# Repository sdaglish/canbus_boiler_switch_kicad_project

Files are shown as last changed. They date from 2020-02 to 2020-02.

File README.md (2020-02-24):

# Canbus Boiler Switch KiCad Project

## Version History

* v1.0
    * 23 Feb 2020
        * First manufactured prototype of board
        * Developed for prototyping
        * Developed for extending to sensor, ect. via header pins
* v1.1
    * 23 Feb 2020
        * Adding version history to readme
        * Removed mfr files from project
        * Removed backup files from project
        * Added sheet information to schematic files

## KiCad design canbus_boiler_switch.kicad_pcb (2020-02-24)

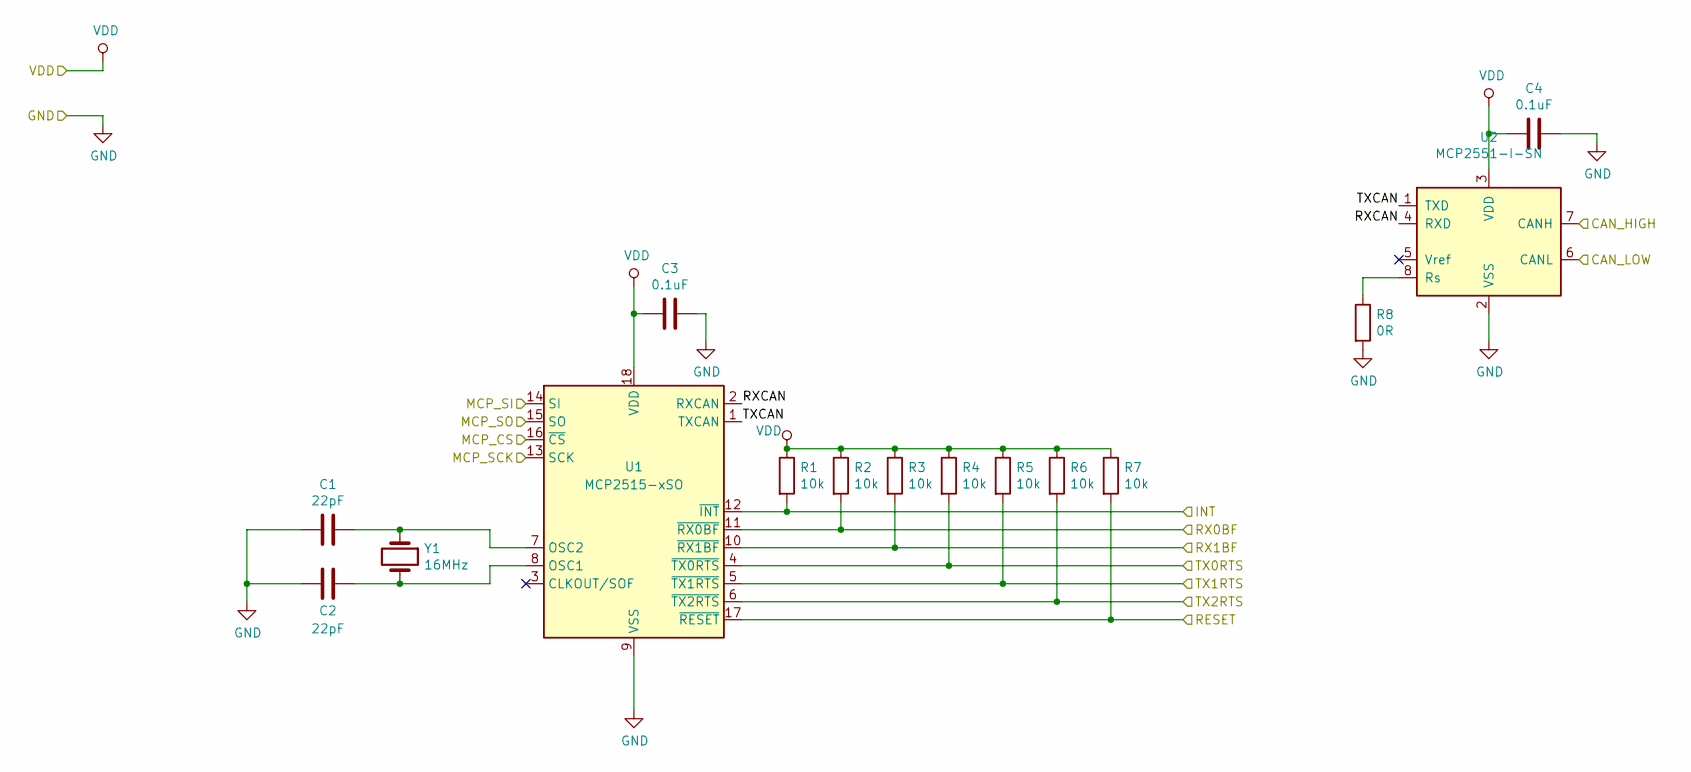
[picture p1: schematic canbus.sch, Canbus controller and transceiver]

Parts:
C1, C2: 22pF; C_1206_3216Metric
C3, C4: 0.1uF; C_1206_3216Metric
R1, R2, R3, R4, R5, R6, R7: 10k; R_1206_3216Metric
R8: 0R; R_1206_3216Metric
U1: MCP2515-xSO; SOIC-18W_7.5x11.6mm_P1.27mm
U2: MCP2551-I-SN; SOIC-8_3.9x4.9mm_P1.27mm
Y1: 16MHz; Crystal_SMD_HC49-SD_HandSoldering

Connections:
/canbus/INT: R1.2, U1.12 (~INT); also elsewhere on the board
/canbus/MCP_SCK: U1.13 (SCK); also elsewhere on the board
/canbus/MCP_SI: U1.14 (SI); also elsewhere on the board
/canbus/MCP_SO: U1.15 (SO); also elsewhere on the board
/canbus/RESET: R7.2, U1.17 (~RESET); also elsewhere on the board
/canbus/RX0BF: R2.2, U1.11 (~RX0BF); also elsewhere on the board
/canbus/RX1BF: R3.2, U1.10 (~RX1BF); also elsewhere on the board
/canbus/RXCAN: U1.2 (RXCAN), U2.4 (RXD)
/canbus/TX0RTS: R4.2, U1.4 (~TX0RTS); also elsewhere on the board
/canbus/TX1RTS: R5.2, U1.5 (~TX1RTS); also elsewhere on the board
/canbus/TX2RTS: R6.2, U1.6 (~TX2RTS); also elsewhere on the board
/canbus/TXCAN: U1.1 (TXCAN), U2.1 (TXD)
/mircoprocessor/CS: U1.16 (~CS); also elsewhere on the board
/rj12_connections/CAN_H: U2.7 (CANH); also elsewhere on the board
/rj12_connections/CAN_L: U2.6 (CANL); also elsewhere on the board
GND: C1.2, C2.2, C3.1, C4.1, R8.2, U1.9 (VSS), U2.2 (VSS); also elsewhere on the board
unnamed: C1.1, U1.7 (OSC2), Y1.1
unnamed: C2.1, U1.8 (OSC1), Y1.2
unnamed: R8.1, U2.8 (Rs)
VDD: C3.2, C4.2, R1.1, R2.1, R3.1, R4.1, R5.1, R6.1, R7.1, U1.18 (VDD), U2.3 (VDD); also elsewhere on the board

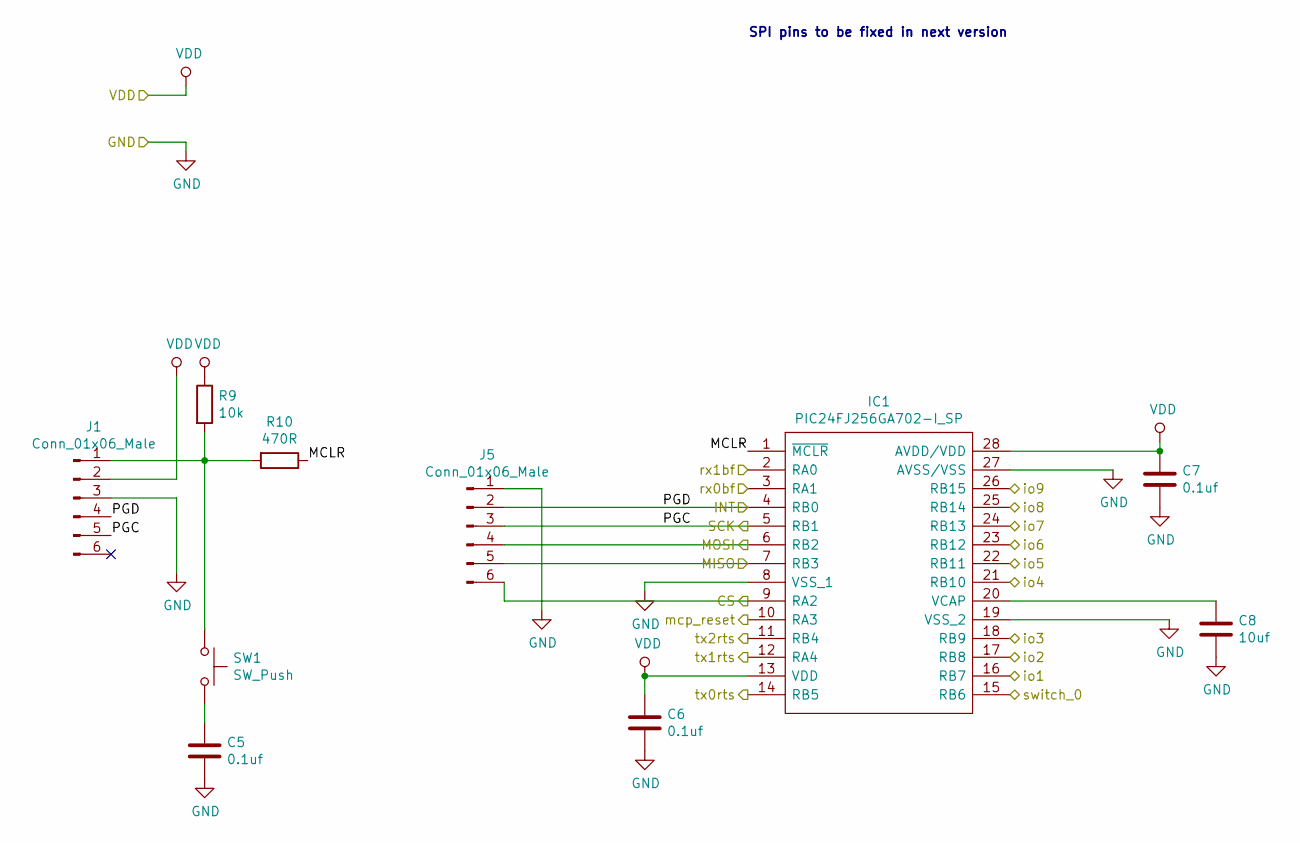
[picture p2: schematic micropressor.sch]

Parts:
C5, C6, C7: 0.1uf; C_1206_3216Metric
C8: 10uf; C_1206_3216Metric
IC1: PIC24FJ256GA702-I_SP; SOIC127P1030X265-28N; Manufacturer_Part_Number PIC24FJ256GA702-I/SP; Mouser Part Number 579-24FJ256GA702ISP
J1, J5: Conn_01x06_Male; PinHeader_1x06_P2.54mm_Vertical
R9: 10k; R_1206_3216Metric
R10: 470R; R_1206_3216Metric
SW1: SW_Push; SW_PUSH_6mm

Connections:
/canbus/INT: IC1.4 (RB0), J1.4, J5.2; also elsewhere on the board
/canbus/MCP_SCK: IC1.5 (RB1), J1.5, J5.3; also elsewhere on the board
/canbus/MCP_SI: IC1.6 (RB2), J5.4; also elsewhere on the board
/canbus/MCP_SO: IC1.7 (RB3), J5.5; also elsewhere on the board
/canbus/RESET: IC1.10 (RA3); also elsewhere on the board
/canbus/RX0BF: IC1.3 (RA1); also elsewhere on the board
/canbus/RX1BF: IC1.2 (RA0); also elsewhere on the board
/canbus/TX0RTS: IC1.14 (RB5); also elsewhere on the board
/canbus/TX1RTS: IC1.12 (RA4); also elsewhere on the board
/canbus/TX2RTS: IC1.11 (RB4); also elsewhere on the board
/io/io1: IC1.16 (RB7); also elsewhere on the board
/io/io2: IC1.17 (RB8); also elsewhere on the board
/io/io3: IC1.18 (RB9); also elsewhere on the board
/io/io4: IC1.21 (RB10); also elsewhere on the board
/io/io5: IC1.22 (RB11); also elsewhere on the board
/io/io6: IC1.23 (RB12); also elsewhere on the board
/io/io7: IC1.24 (RB13); also elsewhere on the board
/io/io8: IC1.25 (RB14); also elsewhere on the board
/io/io9: IC1.26 (RB15); also elsewhere on the board
/io/switch_0: IC1.15 (RB6); also elsewhere on the board
/mircoprocessor/CS: IC1.9 (RA2), J5.6; also elsewhere on the board
/mircoprocessor/MCLR: IC1.1 (~MCLR), R10.1
GND: C5.2, C6.2, C7.2, C8.2, IC1.8 (VSS_1), IC1.19 (VSS_2), IC1.27 (AVSS/VSS), J1.3, J5.1; also elsewhere on the board
unnamed: C5.1, SW1.2
unnamed: C8.1, IC1.20 (VCAP)
unnamed: J1.1, R9.2, R10.2, SW1.1
VDD: C6.1, C7.1, IC1.13 (VDD), IC1.28 (AVDD/VDD), J1.2, R9.1; also elsewhere on the board

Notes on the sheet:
SPI pins to be fixed in next version

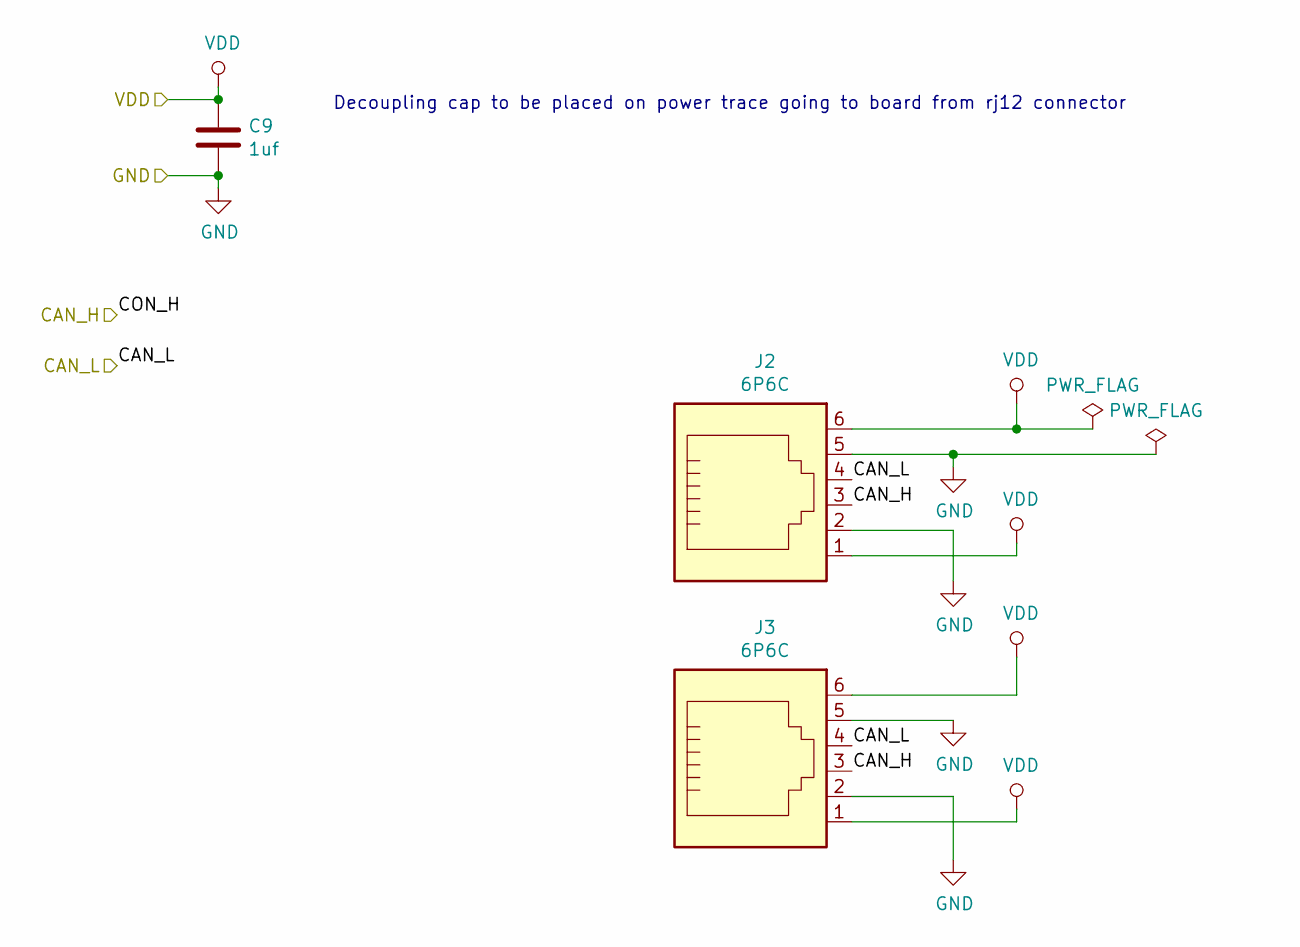
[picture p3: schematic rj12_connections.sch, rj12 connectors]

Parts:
C9: 1uf; C_1206_3216Metric
J2, J3: 6P6C; RJ12_Amphenol_54601

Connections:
/rj12_connections/CAN_H: J2.3, J3.3; also elsewhere on the board
/rj12_connections/CAN_L: J2.4, J3.4; also elsewhere on the board
GND: C9.2, J2.2, J2.5, J3.2, J3.5; also elsewhere on the board
VDD: C9.1, J2.1, J2.6, J3.1, J3.6; also elsewhere on the board

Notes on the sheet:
Decoupling cap to be placed on power trace going to board from rj12 connector

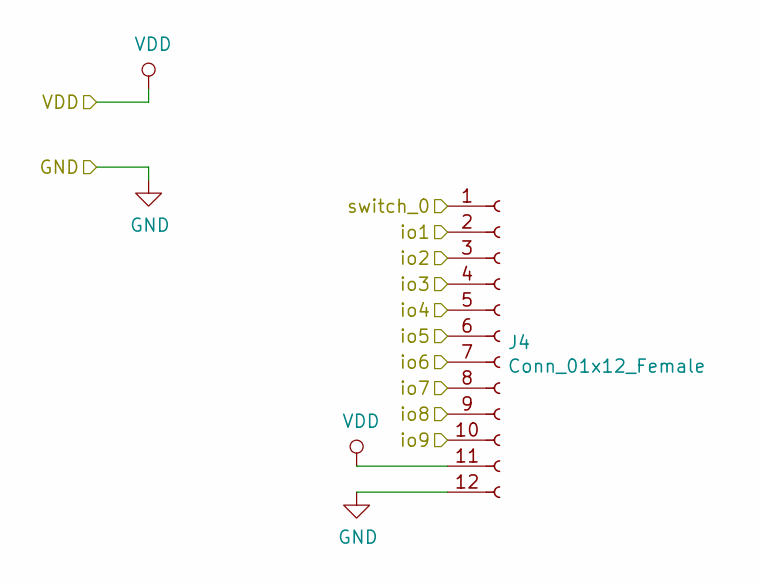
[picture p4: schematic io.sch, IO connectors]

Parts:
J4: Conn_01x12_Female; PinSocket_1x12_P2.54mm_Vertical

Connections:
/io/io1: J4.2; also elsewhere on the board
/io/io2: J4.3; also elsewhere on the board
/io/io3: J4.4; also elsewhere on the board
/io/io4: J4.5; also elsewhere on the board
/io/io5: J4.6; also elsewhere on the board
/io/io6: J4.7; also elsewhere on the board
/io/io7: J4.8; also elsewhere on the board
/io/io8: J4.9; also elsewhere on the board
/io/io9: J4.10; also elsewhere on the board
/io/switch_0: J4.1; also elsewhere on the board
GND: J4.12; also elsewhere on the board
VDD: J4.11; also elsewhere on the board

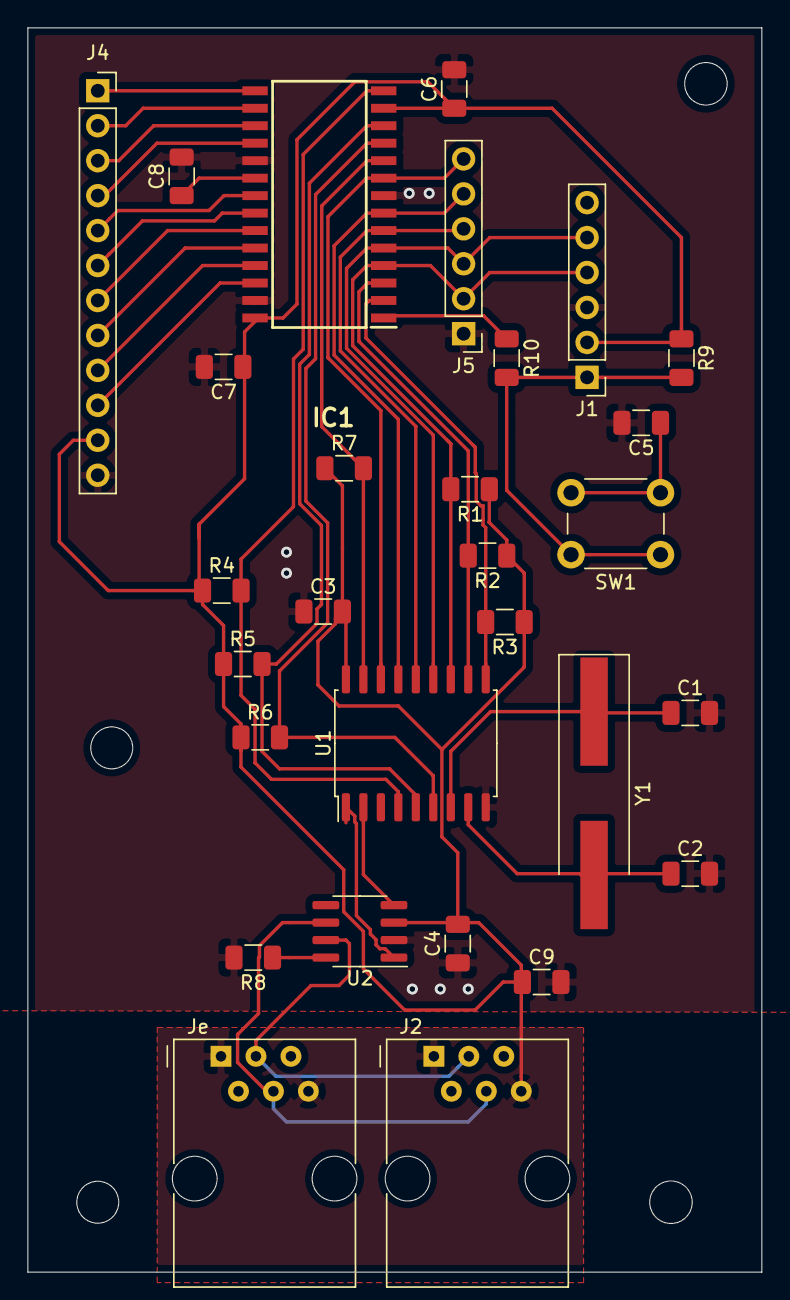
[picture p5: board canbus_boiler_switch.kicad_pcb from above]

Board: 2 copper layers, 53.3 x 90.4 mm, 29 parts (0 on the bottom side), 34 nets.

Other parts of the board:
Je: 6P6C; RJ12_Amphenol_54601

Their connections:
/rj12_connections/CAN_H: Je.3; also elsewhere on the board
/rj12_connections/CAN_L: Je.4; also elsewhere on the board
GND: Je.2, Je.5; also elsewhere on the board
VDD: Je.1, Je.6; also elsewhere on the board

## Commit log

2019-10-19 Project creation
    [canbus_boiler_switch.kicad_pcb, canbus_boiler_switch.sch]
2020-02-23 Finishing up
    [canbus.sch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]
2020-02-23 Removing mfr files
    [canbus_boiler_switch-B_Adhes.gbr, canbus_boiler_switch-B_CrtYd.gbr, canbus_boiler_switch-B_Cu.gbr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]
2020-02-24 Further page information added to schematic sheets
    [canbus.sch, canbus_boiler_switch.sch, io.sch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]
2020-02-24 Added page information to pcb sheet
    [canbus_boiler_switch.kicad_pcb]
2020-02-24 Note added to fix SPI pin in next revision
    [micropressor.sch]
